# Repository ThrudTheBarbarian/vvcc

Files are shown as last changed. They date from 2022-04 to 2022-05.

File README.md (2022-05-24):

# vvcc
Variable-VCC circuit using an RP2040

This is a test-board to try out using a variable-pot controlled by an RP2040 to 
in turn control the voltage of a voltage regulator. That voltage will then be
provided to the other side of a level-shifter to insulate an FPGA from different
voltage inputs.

The level shifter in question can run at >400 MHz, which is the max toggle frequency of
the FPGA.

Simultaneously, I wanted to test out the USB component of the RP2040 and make sure I had
the design correct before laying down the FPGA board (which is a lot more expensive). the
RP2040 will be the last bastion against a bricked FPGA, so it'd be good to know that 
worked too.

So basically a testing-ground. Enjoy.

Thrud

# Update 25/May/2022

Boards came back today, with slightly mixed results. Plugging the first board in, the leds flickered, presumably magic smoke exited stage left, and the 3.3v power rail was churning out 1.1v...

Checking everything against the schematic, it seemed ok, nothing was placed the wrong way around, and even running through the boot process and (re)checking the default value for the I2C-controlled resistance looked like the resulting voltage from IC5 would be ok (4.3v by default).

I was left wondering whether the boot process did weird things with GPIOs, which seems vanishingly unlikely, but ... Anyway, holding down reset & boot buttons on a second board made that boot up ok, appear as RPI2_BOOT on the Mac, and none of the LEDs flashed, 3.3v rail seems ok (LED lights) etc. 

So my advice is that if you get these made, make sure you initialise it with known firmware before letting it boot on its own. 

Note: There is a pullup missing on the /CS line for the flash, but it's also missing in the RP2040 hardware design guide with the comment that they found they didn't need it. I'll definitely include it in future mind.

If booting it with working firmware still results in a problem, I'll update this. It's also possible the first board was just a dud... Once I have tested out the firmware thing, I might try sacrificing another board to see if it has the same behaviour as the first when booted up with no firmware in place.

Thrud

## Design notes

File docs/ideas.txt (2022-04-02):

Ideas for test-board

- Make sure we have one of the level-translators on-board

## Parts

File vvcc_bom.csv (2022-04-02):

Qty | Value | Device | Package | Parts | Description | ARROW_PART_NUMBER | ARROW_PRICE-STOCK | DESCRIPTION | HEIGHT | MANUFACTURER_NAME | MANUFACTURER_PART_NUMBER | MOUSER_PART_NUMBER | MOUSER_PRICE-STOCK | POPULARITY | SPICEPREFIX | USE
1 |  | PINHD-2X5 | 2X05 | JP1 | PIN HEADER |  |  |  |  |  |  |  |  | 35 |  | TSHS-105-D-06-A-T-LF
16 | 100nF | C-EUC0201 | C0201 | C1, C4, C5, C6, C7, C8, C9, C10, C11, C12, C14, C15, C16, C24, C25, C26 | CAPACITOR, European symbol |  |  |  |  |  |  |  |  | 0 | C | 0201X104M160CT
1 | 100nF | C-EUC0201 | C0201 | C18 | CAPACITOR, European symbol |  |  |  |  |  |  |  |  | 0 | C | GRM033R61A104ME15D
4 | 10K | R-EU_R0201 | R0201 | R7, R8, R9, R10 | RESISTOR, European symbol |  |  |  |  |  |  |  |  | 0 | R | CR0201-JW-103GLF
5 | 10uF | C-EUC0402 | C0402 | C2, C3, C21, C22, C23 | CAPACITOR, European symbol |  |  |  |  |  |  |  |  | 18 | C | GRM155R60J106ME15D
1 | 10uF | C-EUC0402K | C0402K | C17 | CAPACITOR, European symbol |  |  |  |  |  |  |  |  | 15 | C | CL05A106MP5NUNC
1 | 12MHz | ABLS-12.000MHZ-B4-T | HC/49US-(AT49)_1 | Q1 | ABRACON - ABLS-12.000MHZ-B4-T - CRYSTAL, 12MHZ, 18PF, HC-49US | ABLS-12.000MHZ-B4-T | https://www.arrow.com/en/products/abls-12.000mhz-b4-t/abracon?region=nac | ABRACON - ABLS-12.000MHZ-B4-T - CRYSTAL, 12MHZ, 18PF, HC-49US | mm | ABRACON | ABLS-12.000MHZ-B4-T | 815-ABLS-12.0M-T | https://www.mouser.co.uk/ProductDetail/ABRACON/ABLS-12000MHZ-B4-T?qs=yTU0IcKoRlGSQ8ooxPPVnQ%3D%3D |  |  | ABLS-12.000MHZ-B4-T
1 | 16MB_Flash | W25Q128JVSIM_TR | SOIC127P790X216-8N | IC4 | 3V 128M-BIT SERIAL FLASH MEMORY WITH DUAL/QUAD SPI & QPI & DTR | W25Q128JVSIM TR | https://www.arrow.com/en/products/w25q128jvsimtr/winbond-electronics?region=nac | 3V 128M-BIT SERIAL FLASH MEMORY WITH DUAL/QUAD SPI & QPI & DTR | 2.16mm | Winbond | W25Q128JVSIM TR | 454-W25Q128JVSIMTR | https://www.mouser.co.uk/ProductDetail/Winbond/W25Q128JVSIM-TR?qs=qSfuJ%252Bfl%2Fd6ji9IuruL6Zg%3D%3D |  |  | W25Q128JVSIM
3 | 1K | R-EU_R0201 | R0201 | R3, R4, R11 | RESISTOR, European symbol |  |  |  |  |  |  |  |  | 0 | R | RC0201FR-071KL
2 | 1uF | C-EUC0201 | C0201 | C13, C27 | CAPACITOR, European symbol |  |  |  |  |  |  |  |  | 0 | C | 0201B102K250CT
2 | 27R4 | R-EU_R0201 | R0201 | R1, R2 | RESISTOR, European symbol |  |  |  |  |  |  |  |  | 0 | R | RC0201FR-0727R4L
2 | 27pF | C-EUC0201 | C0201 | C19, C20 | CAPACITOR, European symbol |  |  |  |  |  |  |  |  | 0 | C | C0201C270J3GAC7867
2 | 302-S301 | 302-S301 | SHDR30W66P254_2X15_4572X910X91 | J2, J3 | Dual row vertical box header | 302-S301 | https://www.arrow.com/en/products/302-s301/on-shore-technology | Dual row vertical box header | 9.1mm | On-Shore Technology, Inc | 302-S301 |  |  |  |  | 302-S301
2 | 4K7 | R-EU_R0201 | R0201 | R5, R6 | RESISTOR, European symbol |  |  |  |  |  |  |  |  | 0 | R | ERJ-1GNJ472C
1 | CLXC8T245QRHLRQ1 | CLXC8T245QRHLRQ1 | CLXC8T245QRHLRQ1 | IC6 | Translation - Voltage Levels Automotive 8-bit dual-supply wide voltage level translating transceiver with tri-state output | CLXC8T245QRHLRQ1 | https://www.arrow.com/en/products/clxc8t245qrhlrq1/texas-instruments?region=nac | Translation - Voltage Levels Automotive 8-bit dual-supply wide voltage level translating transceiver with tri-state output | 1mm | Texas Instruments | CLXC8T245QRHLRQ1 | 595-CLXC8T245QRHLRQ1 | https://www.mouser.co.uk/ProductDetail/Texas-Instruments/CLXC8T245QRHLRQ1?qs=81r%252BiQLm7BTun0cHFvM3vA%3D%3D |  |  | CLXC8T245QRHLRQ1
1 | LD117ADT-TR | LD117ADT-TR | DPACK | IC5 | Low drop fixed and adjustable positive voltage regulators 1 A |  |  |  |  |  |  |  |  | 0 |  | LD1117ADT-TR
1 | MCP40D19T-5K | MCP40D18T-104E_LT | SOP65P210X110-6N | IC1 | MCP40D18T-104E/LT, Digital Potentiometer 100k 128-Position Linear Serial-I2C 6-Pin SC-70 | MCP40D18T-104E/LT | https://www.arrow.com/en/products/mcp40d18t-104elt/microchip-technology?region=nac | MCP40D18T-104E/LT, Digital Potentiometer 100k 128-Position Linear Serial-I2C 6-Pin SC-70 | 1.1mm | Microchip | MCP40D18T-104E/LT | 579-MCP40D18T104E/LT | https://www.mouser.co.uk/ProductDetail/Microchip-Technology/MCP40D18T-104E-LT?qs=dQMF8gqycOWA9kQDYIYtyg%3D%3D |  |  | MCP4019T-502E/LT
1 | MIC803-30D3VM3-TR | MIC803-30D2VM3-TR | SOT95P237X111-3N | SPV | Supervisory Circuits 3-Pin Microprocessor Supervisor Circuit w/ Open-Drain Reset Output | MIC803-30D2VM3-TR | https://www.arrow.com/en/products/mic803-30d2vm3-tr/microchip-technology | Supervisory Circuits 3-Pin Microprocessor Supervisor Circuit w/ Open-Drain Reset Output | 1.11mm | Microchip | MIC803-30D2VM3-TR | 998-MIC803-30D2VM3TR | https://www.mouser.co.uk/ProductDetail/Microchip-Technology-Micrel/MIC803-30D2VM3-TR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 |  |  | MIC803-30D3VM3-TR
1 | Micro-B | MCR-B-S-RA-SMT-CS14-T_R | MCRBSRASMTCS14TR | J1 | USB - micro B Receptacle Connector 5 Position Surface Mount, Right Angle | MCR-B-S-RA-SMT-CS14-T/R | https://www.arrow.com/en/products/mcr-b-s-ra-smt-cs14-tr/adam-tech?region=nac | USB - micro B Receptacle Connector 5 Position Surface Mount, Right Angle | 3.1mm | Adam Tech | MCR-B-S-RA-SMT-CS14-T/R |  |  |  |  | MCR-B-S-RA-SMT-CS14-T_R
1 | NCP1117LPST33T3G | NCP1117LPST33T3G | SOT230P700X180-4N | IC3 | ON SEMICONDUCTOR - NCP1117LPST33T3G - Fixed LDO Voltage Regulator, 18V in, 1.3V Dropout, 3.3V/1A out, SOT-223-3 | NCP1117LPST33T3G | https://www.arrow.com/en/products/ncp1117lpst33t3g/on-semiconductor?region=nac | ON SEMICONDUCTOR - NCP1117LPST33T3G - Fixed LDO Voltage Regulator, 18V in, 1.3V Dropout, 3.3V/1A out, SOT-223-3 | 1.8mm | ON Semiconductor | NCP1117LPST33T3G | 863-NCP1117LPST33T3G | https://www.mouser.co.uk/ProductDetail/onsemi/NCP1117LPST33T3G?qs=kbSN2QblFfKG9A4Foh4YYg%3D%3D |  |  | NCP1117LPST33T3G
1 | RESET | TAC_SWITCHPTH | TACTILE-PTH | RESET | Momentary Switch |  |  |  |  |  |  |  |  |  |  | B3F-1005
1 | RP2040 | RP2040 | QFN40P700X700X90-57N | IC2 | Microcontroller in QFN Package |  |  | Microcontroller in QFN Package | 0.9mm | RASPBERRY-PI | RP2040 |  |  |  |  | SC0914(13)
1 | USB_BOOT | TAC_SWITCHPTH | TACTILE-PTH | USB_BOOT | Momentary Switch |  |  |  |  |  |  |  |  |  |  | B3F-1005

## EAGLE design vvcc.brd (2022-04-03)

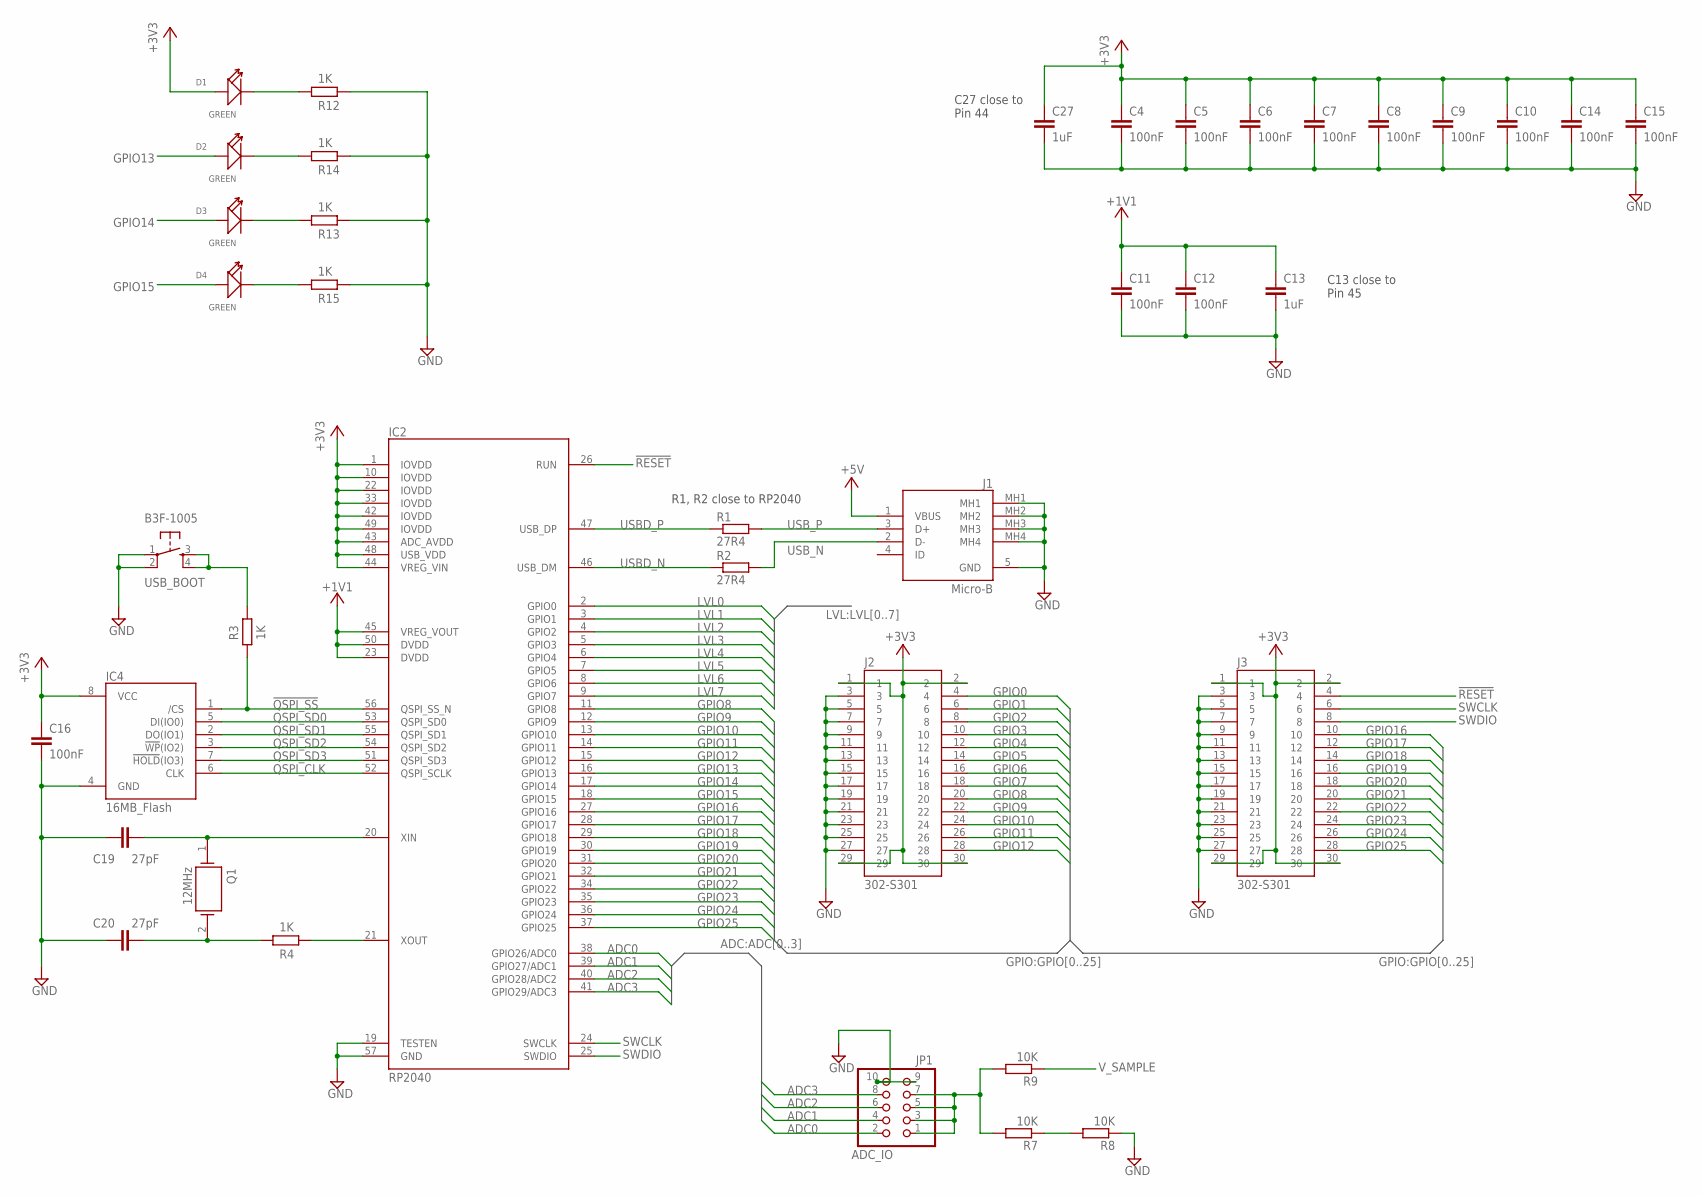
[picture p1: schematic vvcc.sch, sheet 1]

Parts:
C4, C5, C6, C7, C8, C9, C10, C11, C12, C14, C15, C16: 100nF; C0201
C13, C27: 1uF; C0201
C19, C20: 27pF; C0201
D1, D2, D3, D4: GREEN; LED-0603
IC2: RP2040; QFN40P700X700X90-57N
IC4: 16MB_Flash; SOIC127P790X216-8N
J1: Micro-B; MCRBSRASMTCS14TR
J2, J3: 302-S301; SHDR30W66P254_2X15_4572X910X91
JP1: ADC_IO; 2X05
Q1: 12MHz; HC/49US-(AT49)_1
R1, R2: 27R4; R0201
R3, R4, R12, R13, R14, R15: 1K; R0201
R7, R8, R9: 10K; R0201
USB_BOOT: B3F-1005; TACTILE-PTH

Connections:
!QSPI_SS!: IC2.56 (QSPI_SS_N), IC4.1 (/CS), R3.2
!RESET!: IC2.26 (RUN), J3.4; also elsewhere on the board
+1.8_FT: C11.1, C12.1, C13.1, IC2.23 (DVDD), IC2.45 (VREG_VOUT), IC2.50 (DVDD)
+3V3: C4.1, C5.1, C6.1, C7.1, C8.1, C9.1, C10.1, C14.1, C15.1, C16.1, C27.1, D1.+, IC2.1 (IOVDD), IC2.10 (IOVDD), IC2.22 (IOVDD), IC2.33 (IOVDD), IC2.42 (IOVDD), IC2.43 (ADC_AVDD), IC2.44 (VREG_VIN), IC2.48 (USB_VDD), IC2.49 (IOVDD), IC4.8 (VCC), J2.1, J2.2, J2.29, J2.30, J3.1, J3.2, J3.29, J3.30; also elsewhere on the board
+5V: J1.1 (VBUS); also elsewhere on the board
ADC0: IC2.38 (GPIO26/ADC0), JP1.2
ADC1: IC2.39 (GPIO27/ADC1), JP1.4
ADC2: IC2.40 (GPIO28/ADC2), JP1.6
ADC3: IC2.41 (GPIO29/ADC3), JP1.8
GND: C4.2, C5.2, C6.2, C7.2, C8.2, C9.2, C10.2, C11.2, C12.2, C13.2, C14.2, C15.2, C16.2, C19.2, C20.1, C27.2, IC2.19 (TESTEN), IC2.57 (GND), IC4.4 (GND), J1.5 (GND), J1.MH1, J1.MH2, J1.MH3, J1.MH4, J2.3, J2.5, J2.7, J2.9, J2.11, J2.13, J2.15, J2.17, J2.19, J2.21, J2.23, J2.25, J2.27, J3.3, J3.5, J3.7, J3.9, J3.11, J3.13, J3.15, J3.17, J3.19, J3.21, J3.23, J3.25, J3.27, JP1.9, JP1.10, R8.1, R12.2, R13.2, R14.2, R15.2, USB_BOOT.1, USB_BOOT.2; also elsewhere on the board
GPIO0: J2.4; also elsewhere on the board
GPIO1: J2.6; also elsewhere on the board
GPIO2: J2.8; also elsewhere on the board
GPIO3: J2.10; also elsewhere on the board
GPIO4: J2.12; also elsewhere on the board
GPIO5: J2.14; also elsewhere on the board
GPIO6: J2.16; also elsewhere on the board
GPIO7: J2.18; also elsewhere on the board
GPIO8: IC2.11 (GPIO8), J2.20; also elsewhere on the board
GPIO9: IC2.12 (GPIO9), J2.22; also elsewhere on the board
GPIO10: IC2.13 (GPIO10), J2.24
GPIO11: IC2.14 (GPIO11), J2.26
GPIO12: IC2.15 (GPIO12), J2.28; also elsewhere on the board
GPIO13: D2.+, IC2.16 (GPIO13); also elsewhere on the board
GPIO14: D3.+, IC2.17 (GPIO14)
GPIO15: D4.+, IC2.18 (GPIO15)
GPIO16: IC2.27 (GPIO16), J3.10
GPIO17: IC2.28 (GPIO17), J3.12
GPIO18: IC2.29 (GPIO18), J3.14
GPIO19: IC2.30 (GPIO19), J3.16
GPIO20: IC2.31 (GPIO20), J3.18
GPIO21: IC2.32 (GPIO21), J3.20
GPIO22: IC2.34 (GPIO22), J3.22
GPIO23: IC2.35 (GPIO23), J3.24
GPIO24: IC2.36 (GPIO24), J3.26
GPIO25: IC2.37 (GPIO25), J3.28
LVL0: IC2.2 (GPIO0); also elsewhere on the board
LVL1: IC2.3 (GPIO1); also elsewhere on the board
LVL2: IC2.4 (GPIO2); also elsewhere on the board
LVL3: IC2.5 (GPIO3); also elsewhere on the board
LVL4: IC2.6 (GPIO4); also elsewhere on the board
LVL5: IC2.7 (GPIO5); also elsewhere on the board
LVL6: IC2.8 (GPIO6); also elsewhere on the board
LVL7: IC2.9 (GPIO7); also elsewhere on the board
unnamed: C19.1, IC2.20 (XIN), Q1.1
unnamed: C20.2, Q1.2, R4.1
unnamed: D1.-, R12.1
unnamed: D2.-, R14.1
unnamed: R3.1, USB_BOOT.3, USB_BOOT.4
unnamed: D3.-, R13.1
unnamed: IC2.21 (XOUT), R4.2
unnamed: D4.-, R15.1
unnamed: JP1.1, JP1.3, JP1.5, JP1.7, R7.2, R9.2
unnamed: R7.1, R8.2
QSPI_CLK: IC2.52 (QSPI_SCLK), IC4.6 (CLK)
QSPI_SD0: IC2.53 (QSPI_SD0), IC4.5 (DI(IO0))
QSPI_SD1: IC2.55 (QSPI_SD1), IC4.2 (DO(IO1))
QSPI_SD2: IC2.54 (QSPI_SD2), IC4.3 (!WP!(IO2))
QSPI_SD3: IC2.51 (QSPI_SD3), IC4.7 (!HOLD!(IO3))
SWCLK: IC2.24 (SWCLK), J3.6
SWDIO: IC2.25 (SWDIO), J3.8
USBD_N: IC2.46 (USB_DM), R2.1
USBD_P: IC2.47 (USB_DP), R1.1
USB_N: J1.2 (D-), R2.2
USB_P: J1.3 (D+), R1.2
V_SAMPLE: R9.1; also elsewhere on the board

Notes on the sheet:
R1, R2 close to RP2040
C13 close to Pin 45
C27 close to Pin 44

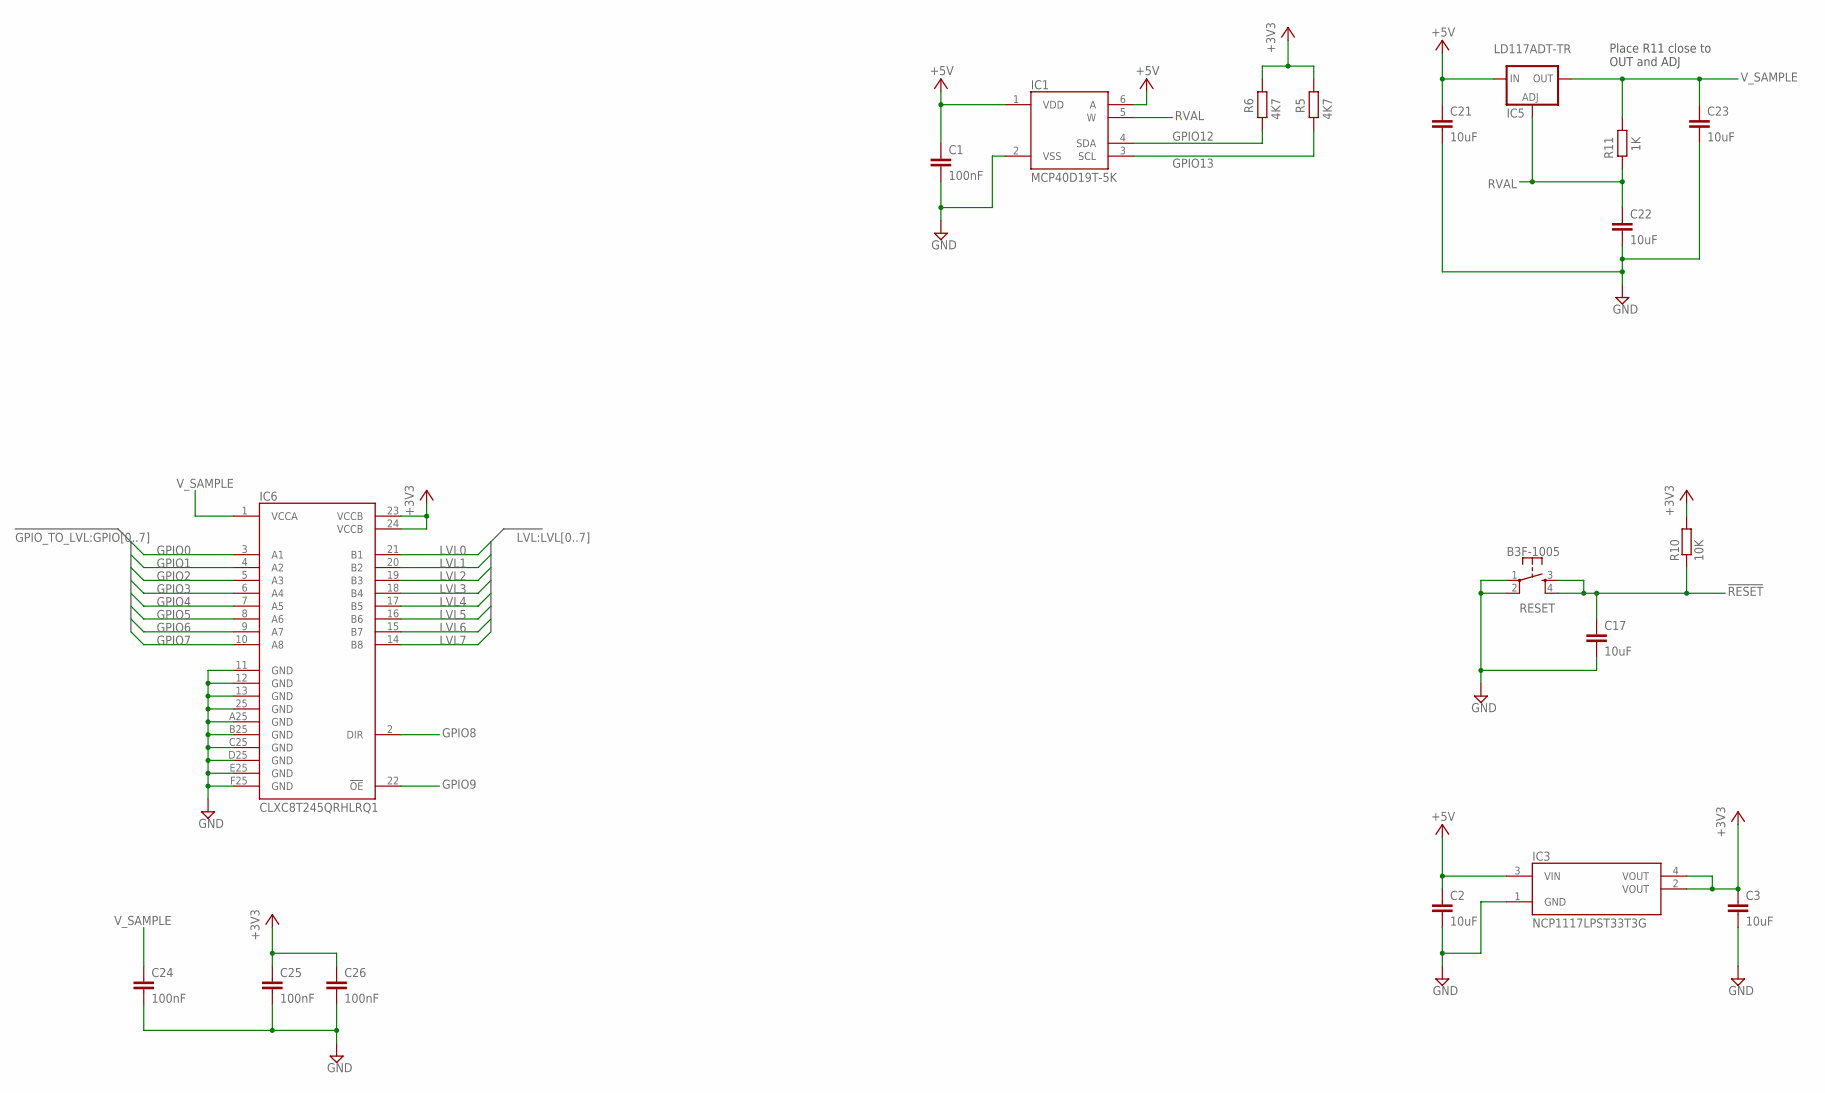
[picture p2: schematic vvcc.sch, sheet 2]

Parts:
C1, C24, C25, C26: 100nF; C0201
C2, C3, C17, C21, C22, C23: 10uF; C0402
IC1: MCP40D19T-5K; SOP65P210X110-6N
IC3: NCP1117LPST33T3G; SOT230P700X180-4N
IC5: LD117ADT-TR; DPACK
IC6: CLXC8T245QRHLRQ1
R5, R6: 4K7; R0201
R10: 10K; R0201
R11: 1K; R0201
RESET: B3F-1005; TACTILE-PTH

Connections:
!RESET!: C17.1, R10.1, RESET.3, RESET.4; also elsewhere on the board
+3V3: C3.1, C25.1, C26.1, IC3.2 (VOUT), IC3.4 (VOUT), IC6.23 (VCCB), IC6.24 (VCCB), R5.1, R6.1, R10.2; also elsewhere on the board
+5V: C1.1, C2.1, C21.1, IC1.1 (VDD), IC1.6 (A), IC3.3 (VIN), IC5.3 (IN); also elsewhere on the board
GND: C1.2, C2.2, C3.2, C17.2, C21.2, C22.2, C23.2, C24.2, C25.2, C26.2, IC1.2 (VSS), IC3.1 (GND), IC6.11 (GND), IC6.12 (GND), IC6.13 (GND), IC6.25 (GND), IC6.A25 (GND), IC6.B25 (GND), IC6.C25 (GND), IC6.D25 (GND), IC6.E25 (GND), IC6.F25 (GND), RESET.1, RESET.2; also elsewhere on the board
GPIO0: IC6.3 (A1); also elsewhere on the board
GPIO1: IC6.4 (A2); also elsewhere on the board
GPIO2: IC6.5 (A3); also elsewhere on the board
GPIO3: IC6.6 (A4); also elsewhere on the board
GPIO4: IC6.7 (A5); also elsewhere on the board
GPIO5: IC6.8 (A6); also elsewhere on the board
GPIO6: IC6.9 (A7); also elsewhere on the board
GPIO7: IC6.10 (A8); also elsewhere on the board
GPIO8: IC6.2 (DIR); also elsewhere on the board
GPIO9: IC6.22 (!OE); also elsewhere on the board
GPIO12: IC1.4 (SDA), R6.2; also elsewhere on the board
GPIO13: IC1.3 (SCL), R5.2; also elsewhere on the board
LVL0: IC6.21 (B1); also elsewhere on the board
LVL1: IC6.20 (B2); also elsewhere on the board
LVL2: IC6.19 (B3); also elsewhere on the board
LVL3: IC6.18 (B4); also elsewhere on the board
LVL4: IC6.17 (B5); also elsewhere on the board
LVL5: IC6.16 (B6); also elsewhere on the board
LVL6: IC6.15 (B7); also elsewhere on the board
LVL7: IC6.14 (B8); also elsewhere on the board
RVAL: C22.1, IC1.5 (W), IC5.1 (ADJ), R11.2
V_SAMPLE: C23.1, C24.1, IC5.4 (OUT), IC6.1 (VCCA), R11.1; also elsewhere on the board

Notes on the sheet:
Place R11 close to OUT and ADJ

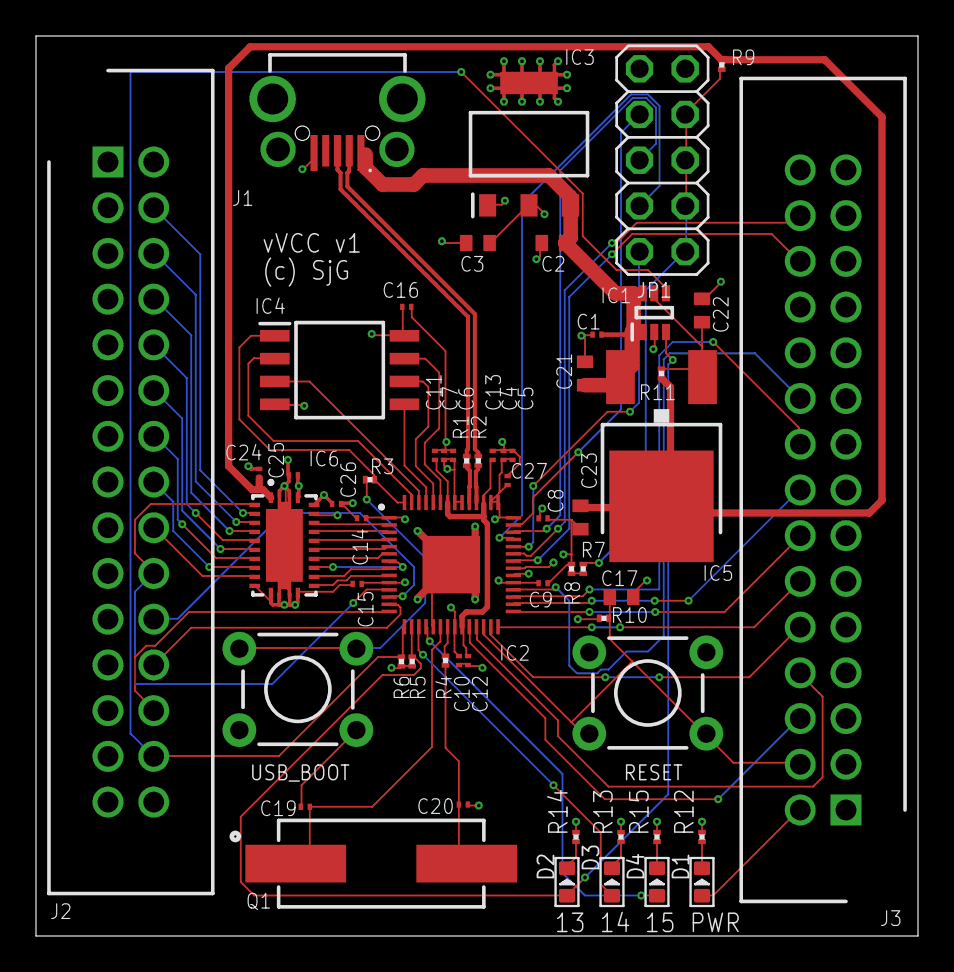
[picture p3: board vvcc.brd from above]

Board: 4 copper layers, 49.0 x 50.0 mm, 58 parts (0 on the bottom side), 67 nets.

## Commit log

2022-04-02 Initial import
    [vvcc.brd, vvcc.sch]
2022-04-02 Change the layout a little to group +5v closer together
    [vvcc.brd]
2022-04-02 Add in a missing 0.1uF capacitor on +3v3
    [vvcc.brd, vvcc.sch]
2022-04-02 Fix a few errors in the schematic. It is good to connect GND to the chip...
    [vvcc.brd, vvcc.sch]
2022-04-02 Make sure everything has a USE attribute
    [vvcc.brd, vvcc.sch, vvcc_bom.csv]
2022-04-02 Submit for creation
    [vvcc.brd, vvcc.sch, vvcc_bom.csv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]
2022-04-03 Better board layout - and added LEDs. This was the real submit to nextpcb
    [vvcc.brd, vvcc.sch, vvcc_bom.csv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]
2022-05-24 Boards came back

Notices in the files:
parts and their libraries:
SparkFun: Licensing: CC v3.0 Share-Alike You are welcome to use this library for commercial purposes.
